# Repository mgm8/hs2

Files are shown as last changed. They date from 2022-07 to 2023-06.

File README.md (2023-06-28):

<h1 align="center">
    HS2
    <br>
</h1>

<h4 align="center">Analog guitar pedal based on Boss HM-2.</h4>

<p align="center">
    <a href="https://github.com/mgm8/hs2">
        
    </a>
    <a href="https://github.com/mgm8/hs2/releases">
        
    </a>
    <a href="https://github.com/mgm8/hs2/blob/main/LICENSE">
        
    </a>
</p>

<p align="center">
    <a href="#overview">Overview</a> •
    <a href="#license">License</a>
</p>

<p align="center">
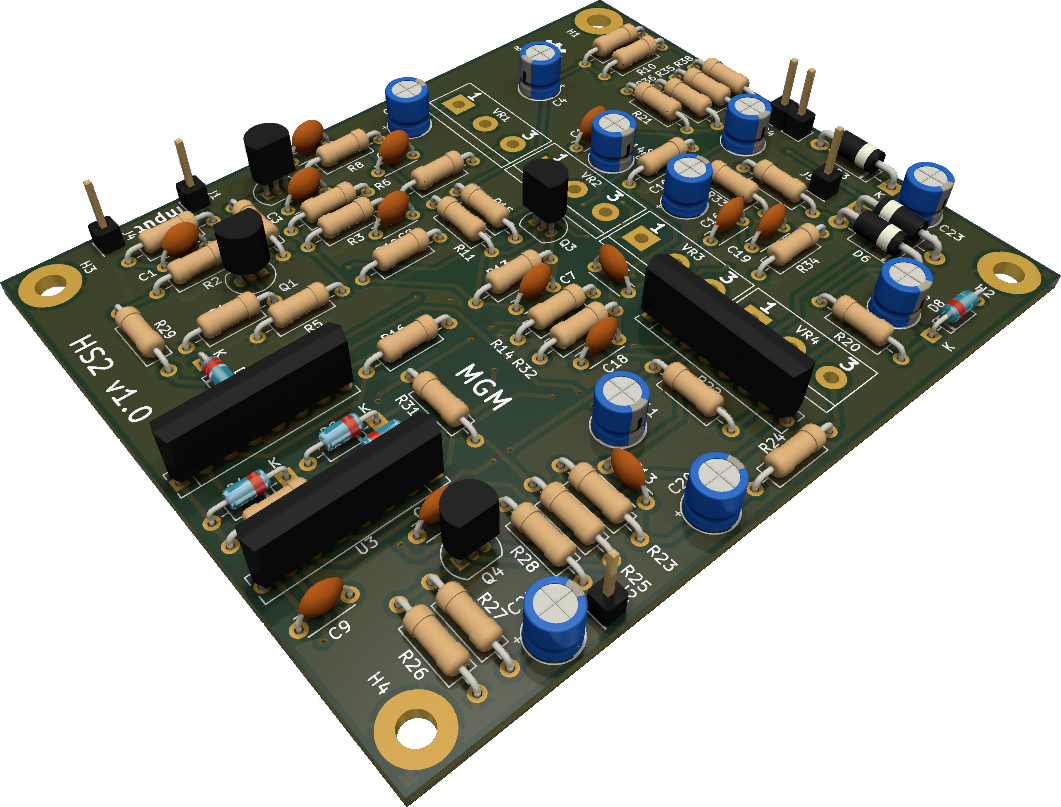
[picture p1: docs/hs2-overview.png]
    
</p>

## Overview

This is an analog guitar pedal based on the Boss HM-2, using the schematics of the project "[The Swede](https://buildyourownclone.myshopify.com/products/the-swede)" as main reference.

## PCB

The Printed Circuit Board of version v1.0 of the project can be seen below:

<p align="center">
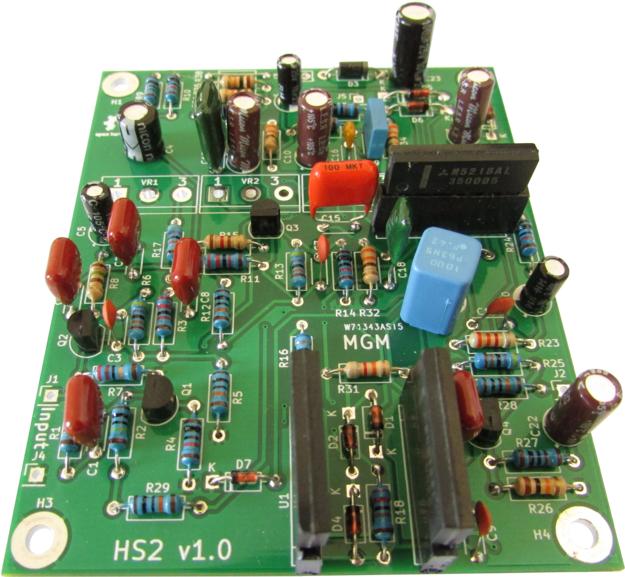
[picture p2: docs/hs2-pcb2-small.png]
    
</p>

This PCB was a courtesy of [PCBWay](https://www.pcbway.com/).

<p align="center">
    
</p>

## Bill of Materials

| ID | Designator | Quantity | Description |
|----|---|---|---|
| 1  | C16 | 1 | Capacitor Film 100nF 25V |
| 2  | R16,R21 | 2 | Resistor 68k 1/4W 1% |
| 3  | C23 | 1 | Capacitor Electrolytic 100uF 25V |
| 4  | C8,C6,C2,C1,C21 | 5 | Capacitor Film 47nF 25V |
| 5  | C11 | 1 | Capacitor Film 1nF 25V |
| 6  | Q1 | 1 | 2N5457 |
| 7  | R26,R35,R24,R10,R4,R14,R1,R36,R20,R19 | 10 | Resistor 10k 1/4W 1% |
| 8  | D8,D4,D1,D7,D2 | 5 | 1N4148 |
| 9  | Q3 | 1 | 2N3906 |
| 10 | D5,D6 | 2 | 1N34A, 1N60, D9E, etc. (Germanium Diodes) |
| 11 | R23,R22 | 2 | Resistor 3k3 1/4W 1% |
| 12 | C24,C5,C20 | 3 | Capacitor Electrolytic 10uF 25V |
| 13 | R7 | 1 | Resistor 22R 1/4W 1% |
| 14 | R2 | 1 | Resistor 1M 1/4W 1% |
| 15 | C12,C10,C22 | 3 | Capacitor Electrolytic 1uF 25V |
| 16 | R30,R34,R38,R32 | 4 | Resistor 330R 1/4W 1% |
| 17 | R12,R28,R29,R33,R5 | 5 | Resistor 100k 1/4W 1% |
| 18 | R18 | 1 | Resistor 220k 1/4W 1% |
| 19 | C19 | 1 | Capacitor Film 4.7nF 25V |
| 20 | U2,U3,U1 | 3 | M5218L |
| 21 | C4 | 1 | Capacitor Electrolytic 47uF 25V |
| 22 | R27,R9 | 2 | Resistor 1k 1/4W 1% |
| 23 | D3 | 1 | 1N4001 |
| 24 | R13,R6,R25 | 3 | Resistor 470k 1/4W 1% |
| 25 | R17 | 1 | Resistor 47k 1/4W 1% |
| 26 | VR1 | 1 | Potentiometer Anti-Log 250k |
| 27 | R31 | 1 | Resistor 82k 1/4W 1% |
| 28 | C13 | 1 | Capacitor Ceramic 470pF 25V |
| 29 | C7,C3,C9 | 3 | Capacitor Ceramic 100pF 25V |
| 30 | R8 | 1 | Resistor 150R 1/4W 1% |
| 31 | VR3,VR2 | 2 | Potentiometer Linear 50k |
| 32 | R11,R3 | 2 | Resistor 22k 1/4W 1% |
| 33 | C17 | 1 | Capacitor Film 68nF 25V |
| 34 | VR4 | 1 | Potentiometer Log 10k |
| 35 | C14 | 1 | Capacitor Electrolytic 1.5uF 25V |
| 36 | C18 | 1 | Capacitor Film 6.8nF 25V |
| 37 | R15 | 1 | Resistor 120R 1/4W 1% |
| 38 | Q2,Q4 | 2 | 2N3904 |
| 39 | C15 | 1 | Capacitor Film 150nF 25V |

## License

This project is licensed under CERN Open Hardware License, version 2.

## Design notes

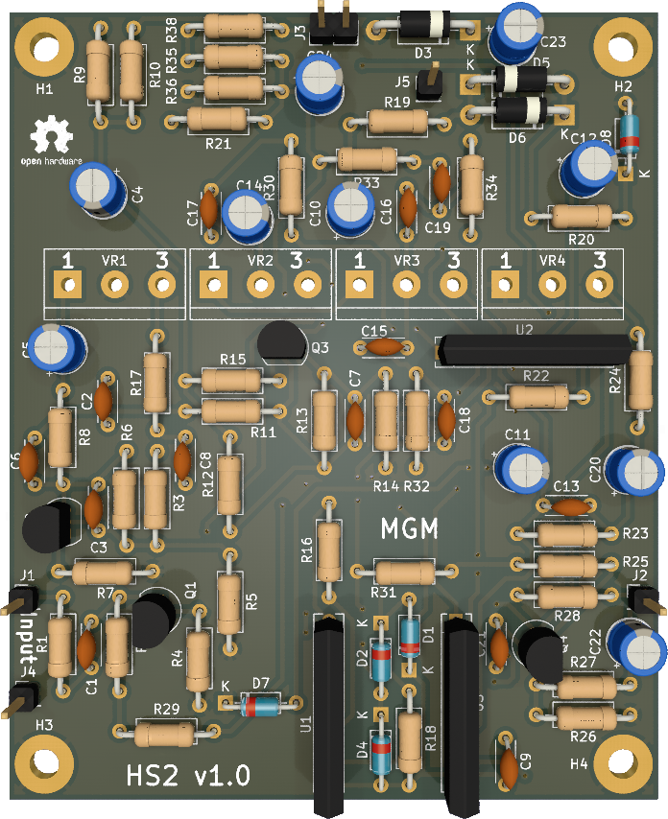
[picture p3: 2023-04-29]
docs/hs2-top.png

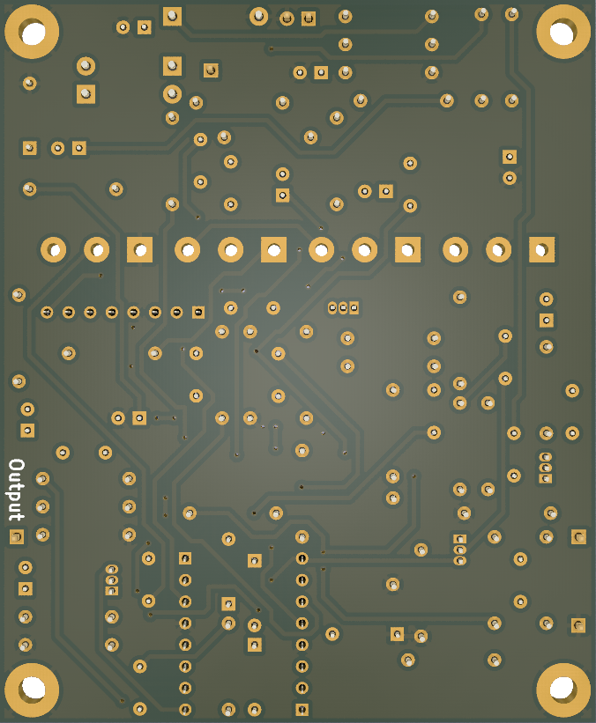
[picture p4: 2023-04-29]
docs/hs2-bottom.png

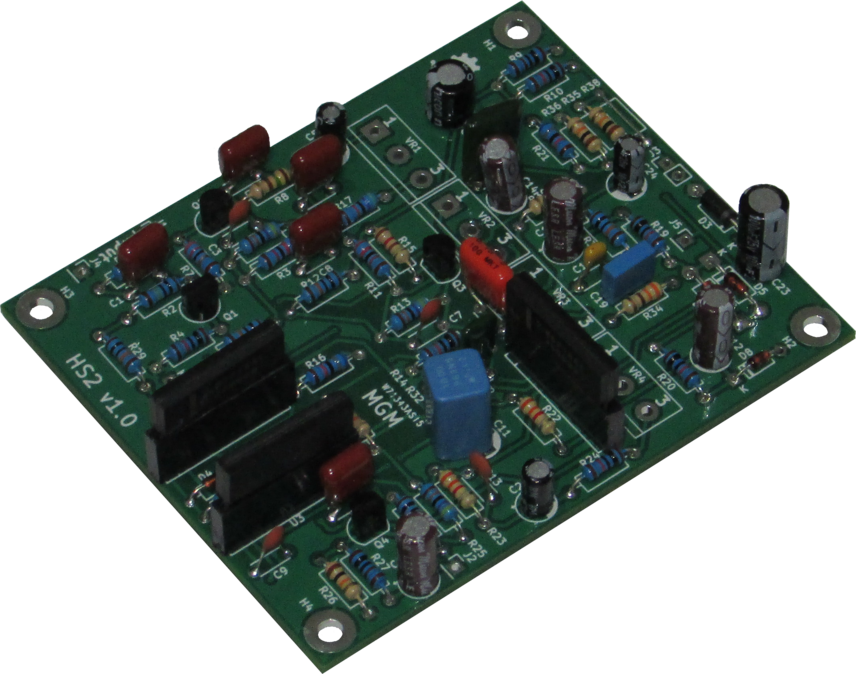
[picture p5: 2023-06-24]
docs/hs2-pcb-small.png

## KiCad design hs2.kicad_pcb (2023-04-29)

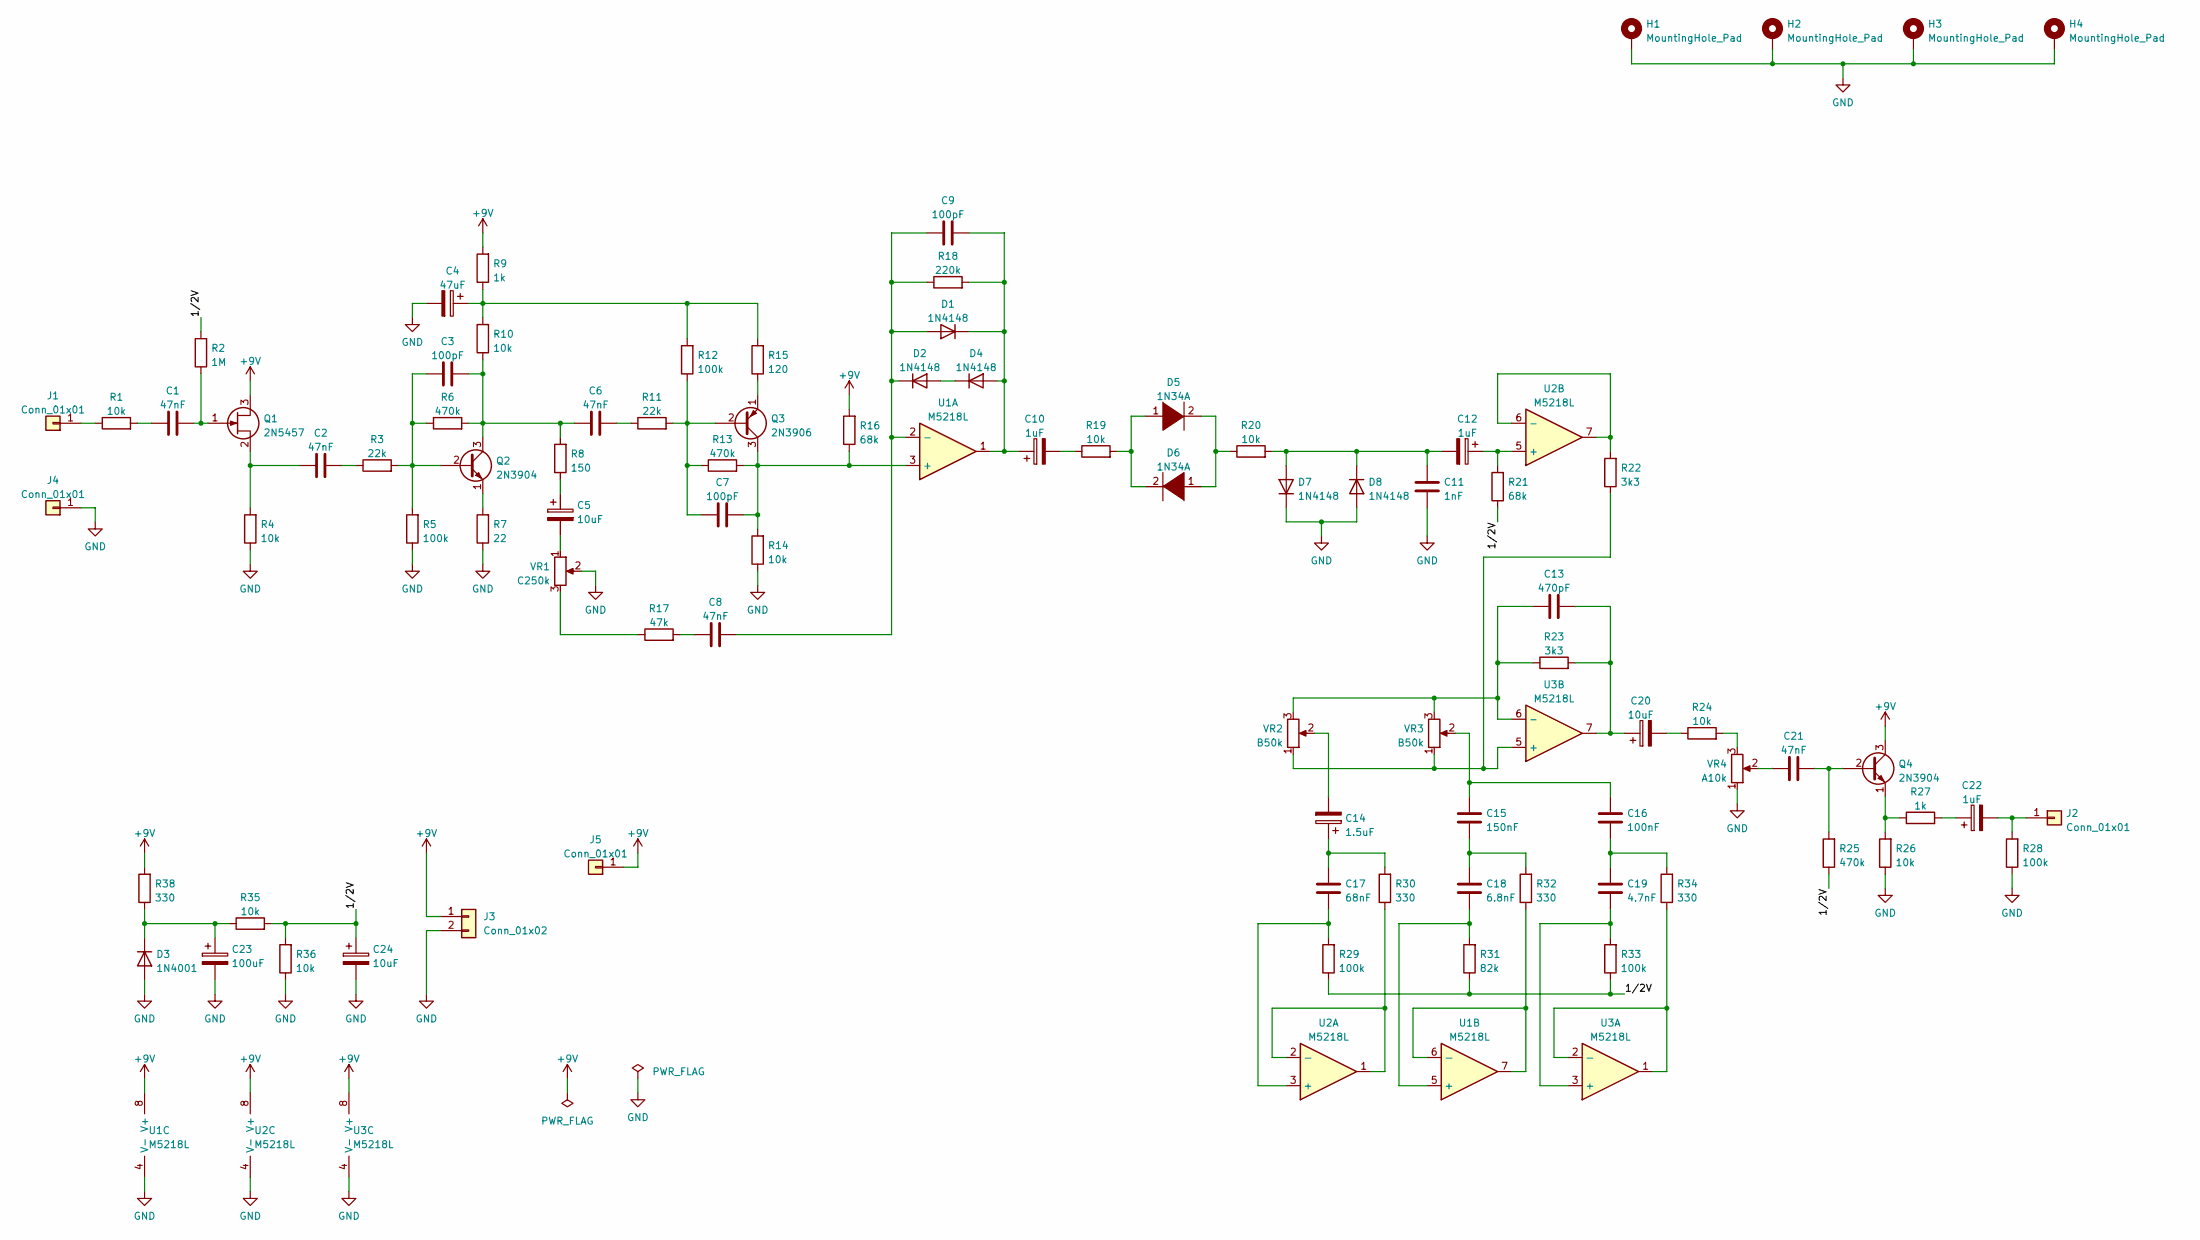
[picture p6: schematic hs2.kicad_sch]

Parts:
C1, C2, C6, C8, C21: 47nF; C_Disc_D4.3mm_W1.9mm_P5.00mm
C3, C7, C9: 100pF; C_Disc_D4.3mm_W1.9mm_P5.00mm
C4: 47uF; CP_Radial_D5.0mm_P2.50mm
C5, C20, C24: 10uF; CP_Radial_D5.0mm_P2.50mm
C10, C12, C22: 1uF; CP_Radial_D5.0mm_P2.50mm
C11: 1nF; CP_Radial_D5.0mm_P2.50mm
C13: 470pF; C_Disc_D4.3mm_W1.9mm_P5.00mm
C14: 1.5uF; CP_Radial_D5.0mm_P2.50mm
C15: 150nF; C_Disc_D4.3mm_W1.9mm_P5.00mm
C16: 100nF; C_Disc_D4.3mm_W1.9mm_P5.00mm
C17: 68nF; C_Disc_D4.3mm_W1.9mm_P5.00mm
C18: 6.8nF; C_Disc_D4.3mm_W1.9mm_P5.00mm
C19: 4.7nF; C_Disc_D4.3mm_W1.9mm_P5.00mm
C23: 100uF; CP_Radial_D5.0mm_P2.50mm
D1, D2, D4, D7, D8: 1N4148; D_DO-35_SOD27_P7.62mm_Horizontal
D3: 1N4001; D_DO-41_SOD81_P10.16mm_Horizontal
D5, D6: 1N34A; D_DO-41_SOD81_P10.16mm_Horizontal
H1, H2, H3, H4: MountingHole_Pad; MountingHole_3.2mm_M3_Pad_TopBottom
J1, J2, J4, J5: Conn_01x01; PinHeader_1x01_P2.54mm_Vertical
J3: Conn_01x02; PinHeader_1x02_P2.54mm_Vertical
Q1: 2N5457; TO-92_Inline
Q2, Q4: 2N3904; TO-92_Inline
Q3: 2N3906; TO-92_Inline
R1, R4, R10, R14, R19, R20, R24, R26, R35, R36: 10k; R_Axial_DIN0207_L6.3mm_D2.5mm_P10.16mm_Horizontal
R2: 1M; R_Axial_DIN0207_L6.3mm_D2.5mm_P10.16mm_Horizontal
R3, R11: 22k; R_Axial_DIN0207_L6.3mm_D2.5mm_P10.16mm_Horizontal
R5, R12, R28, R29, R33: 100k; R_Axial_DIN0207_L6.3mm_D2.5mm_P10.16mm_Horizontal
R6, R13, R25: 470k; R_Axial_DIN0207_L6.3mm_D2.5mm_P10.16mm_Horizontal
R7: 22; R_Axial_DIN0207_L6.3mm_D2.5mm_P10.16mm_Horizontal
R8: 150; R_Axial_DIN0207_L6.3mm_D2.5mm_P10.16mm_Horizontal
R9, R27: 1k; R_Axial_DIN0207_L6.3mm_D2.5mm_P10.16mm_Horizontal
R15: 120; R_Axial_DIN0207_L6.3mm_D2.5mm_P10.16mm_Horizontal
R16, R21: 68k; R_Axial_DIN0207_L6.3mm_D2.5mm_P10.16mm_Horizontal
R17: 47k; R_Axial_DIN0207_L6.3mm_D2.5mm_P10.16mm_Horizontal
R18: 220k; R_Axial_DIN0207_L6.3mm_D2.5mm_P10.16mm_Horizontal
R22, R23: 3k3; R_Axial_DIN0207_L6.3mm_D2.5mm_P10.16mm_Horizontal
R30, R32, R34, R38: 330; R_Axial_DIN0207_L6.3mm_D2.5mm_P10.16mm_Horizontal
R31: 82k; R_Axial_DIN0207_L6.3mm_D2.5mm_P10.16mm_Horizontal
U1, U2, U3: M5218L; SIP-8_19x3mm_P2.54mm
VR1: C250k; TerminalBlock_bornier-3_P5.08mm
VR2, VR3: B50k; TerminalBlock_bornier-3_P5.08mm
VR4: A10k; TerminalBlock_bornier-3_P5.08mm

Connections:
+9V: J3.1, J5.1, Q1.3 (D), Q4.3 (C), R9.2, R16.2, R38.2, U1.8 (V+), U2.8 (V+), U3.8 (V+)
/1/2V: C24.1, R2.2, R21.1, R25.1, R29.1, R31.1, R33.1, R35.2, R36.2
GND: C4.2, C11.2, C23.2, C24.2, D3.2 (A), D7.1 (K), D8.2 (A), H1.1, H2.1, H3.1, H4.1, J3.2, J4.1, R4.1, R5.1, R7.1, R14.1, R26.1, R28.1, R36.1, U1.4 (V-), U2.4 (V-), U3.4 (V-), VR1.2, VR4.1
unnamed: C1.1, R1.2
unnamed: C1.2, Q1.1 (G), R2.1
unnamed: C2.1, Q1.2 (S), R4.2
unnamed: C2.2, R3.1
unnamed: C3.1, Q2.2 (B), R3.2, R5.2, R6.1
unnamed: C3.2, C6.1, Q2.3 (C), R6.2, R8.2, R10.1
unnamed: C4.1, R9.1, R10.2, R12.2, R15.2
unnamed: C5.1, R8.1
unnamed: C5.2, VR1.1
unnamed: C6.2, R11.1
unnamed: C7.1, Q3.2 (B), R11.2, R12.1, R13.1
unnamed: C7.2, Q3.3 (C), R13.2, R14.2, R16.1, U1.3 (+)
unnamed: C8.1, R17.2
unnamed: C8.2, C9.1, D1.2 (A), D2.1 (K), R18.1, U1.2 (-)
unnamed: C9.2, C10.1, D1.1 (K), D4.2 (A), R18.2, U1.1
unnamed: C10.2, R19.1
unnamed: C11.1, C12.2, D7.2 (A), D8.1 (K), R20.2
unnamed: C12.1, R21.2, U2.5 (+)
unnamed: C13.1, R23.1, U3.6 (-), VR2.3, VR3.3
unnamed: C13.2, C20.1, R23.2, U3.7
unnamed: C14.1, C17.1, R30.2
unnamed: C14.2, VR2.2
unnamed: C15.1, C16.1, VR3.2
unnamed: C15.2, C18.1, R32.2
unnamed: C16.2, C19.1, R34.2
unnamed: C17.2, R29.2, U2.3 (+)
unnamed: C18.2, R31.2, U1.5 (+)
unnamed: C19.2, R33.2, U3.3 (+)
unnamed: C20.2, R24.1
unnamed: C21.1, VR4.2
unnamed: C21.2, Q4.2 (B), R25.2
unnamed: C22.1, R27.2
unnamed: C22.2, J2.1, R28.2
unnamed: C23.1, D3.1 (K), R35.1, R38.1
unnamed: D2.2 (A), D4.1 (K)
unnamed: D5.1 (K), D6.2 (A), R19.2
unnamed: D5.2 (A), D6.1 (K), R20.1
unnamed: J1.1, R1.1
unnamed: Q2.1 (E), R7.2
unnamed: Q3.1 (E), R15.1
unnamed: Q4.1 (E), R26.2, R27.1
unnamed: R17.1, VR1.3
unnamed: R22.1, U3.5 (+), VR2.1, VR3.1
unnamed: R22.2, U2.6 (-), U2.7
unnamed: R24.2, VR4.3
unnamed: R30.1, U2.1, U2.2 (-)
unnamed: R32.1, U1.6 (-), U1.7
unnamed: R34.1, U3.1, U3.2 (-)

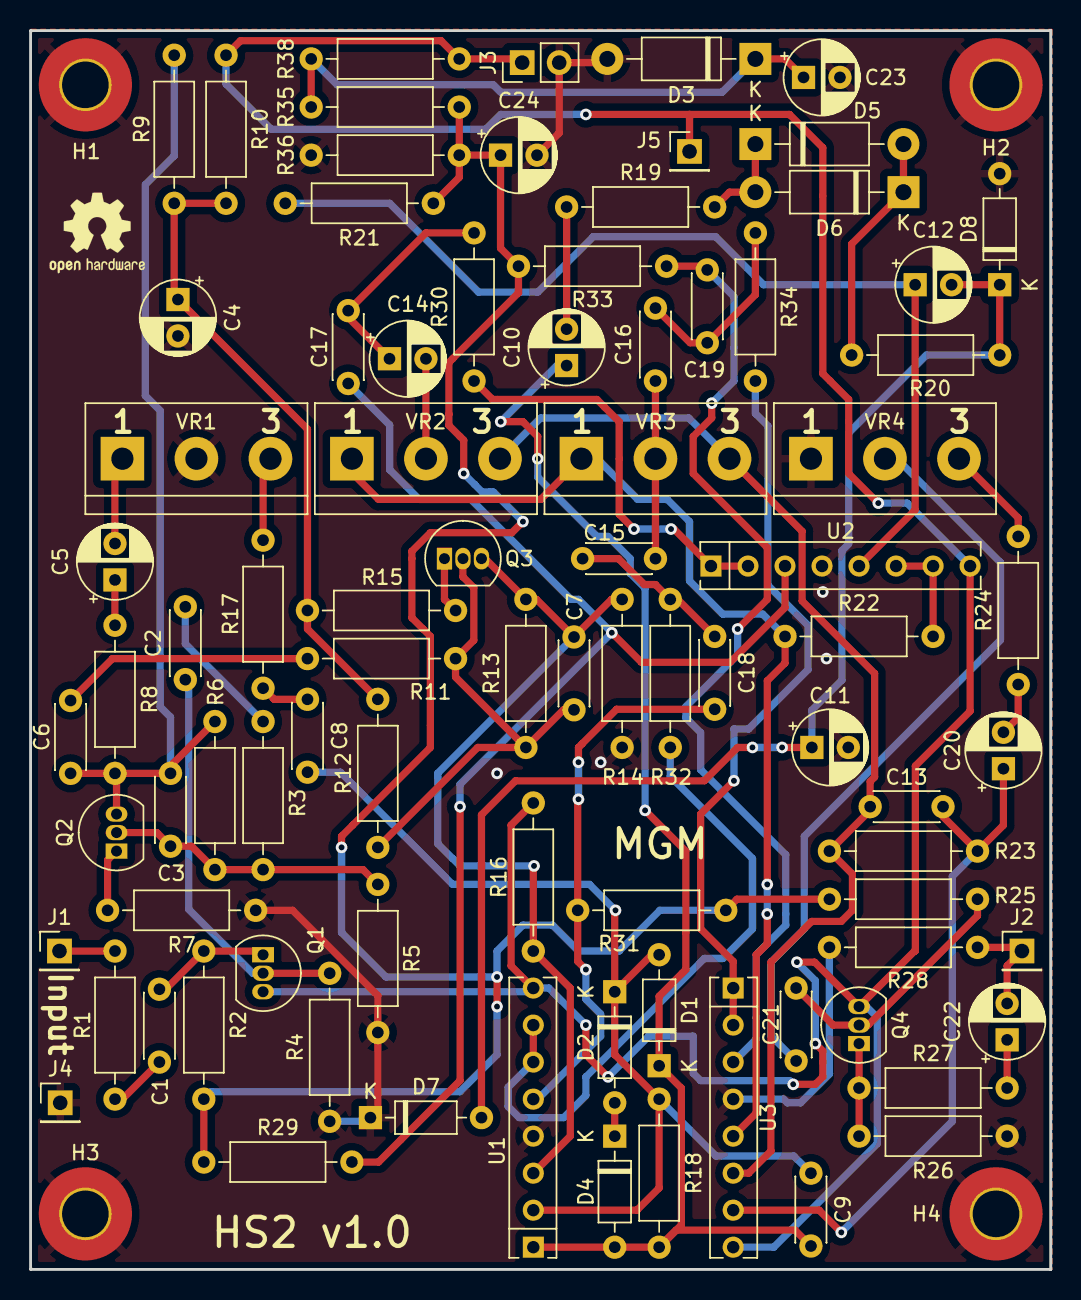
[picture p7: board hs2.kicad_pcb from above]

Board: 2 copper layers, 70.0 x 85.0 mm, 89 parts (0 on the bottom side), 51 nets.

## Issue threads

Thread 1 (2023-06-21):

Fix the footprint of C11

mgm8, 2023-06-21:
C11 is a film capacitor, not a electrolytic capacitor!

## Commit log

2022-07-22 Creating the project in KiCad
    [hm2.kicad_pcb, hm2.kicad_sch]
2022-07-22 schematics: Placing symbols
    [hm2.kicad_sch]
2022-07-24 Renaming the project
    [hs2.kicad_pcb, hs2.kicad_sch]
2022-08-02 schematics: Drawing the circuit
    [hs2.kicad_sch]
2022-08-09 schematics: First version of the schematics
    [hs2.kicad_sch]
2022-08-11 Updating the designators and initial footprint assignment
    [hs2.kicad_sch]
2023-04-22 layout: Components placement
    [hs2.kicad_pcb, hs2.kicad_sch]
2023-04-22 layout: Routing finished
    [hs2.kicad_pcb]
2023-04-22 layout: Adding logos and text
    [hs2.kicad_pcb]
2023-04-22 layout: Fixing the position of the labels
    [hs2.kicad_pcb]
2023-04-22 Updating the main README and adding a 3D render of the PCB
2023-04-23 schematics: Fixing ERC errors
    [hs2.kicad_sch]
2023-04-24 layout: Fixing DRC warnings
    [hs2.kicad_pcb]
2023-04-24 Minor improvements
    [hs2.kicad_pcb, hs2.kicad_sch]
2023-04-29 Adding the BOM to the README file
2023-04-29 Minor fixes in the schematics
    [hs2.kicad_pcb, hs2.kicad_sch]
2023-06-24 Adding pictures of the PCB and updating the main README
2023-06-28 Updating the main README with a section about the PCB prototype

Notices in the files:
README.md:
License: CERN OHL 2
